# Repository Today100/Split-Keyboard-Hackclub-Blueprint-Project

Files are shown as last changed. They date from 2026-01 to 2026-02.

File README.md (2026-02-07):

# Split-Keyboard-Hackclub-Blueprint-Project
A split keyboard using the Seeed Studio XIAO nRF52840. Inspired by my dad, who likes looking at different kinds of keyboards. I'd like to make one to practice my skills in hardware design and give it to him as a gift. It has a Bluetooth feature and is rechargeable.

### Overview

|Part|Image|
|---|---|
|Full Product||
|Case||
|PCB||
|Schematics||

### BOM
BOM.csv is available for review

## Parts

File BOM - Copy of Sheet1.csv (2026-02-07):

Item | Amount | Amount | Store | Unit Price (USD) | Shipping (USD) | Tax (USD) | Total (USD) | Unit Price (CAD) | Shipping (CAD) | Tax (CAD) | Total (CAD) | Link
MBK Low Profile PBT Blank Keycaps Ocean | 6 (packs of 10) | 6 | Lowprokb | $4.38 | $7.30 | $4.36 | $37.94 | $6.00 | $10.00 | $5.98 | $51.98 | link
Kailh Choc V1 Low Profile Switches Red |  |  | Aliexpress | $21.01 | $5.32 | $0.00 | $62.45 | $28.79 | $7.29 | $0.00 | $85.60 | link
Kailh Choc Hot Swap Sockets CPG135001S30 |  |  |  | $14.52 |  |  |  | $19.89 |  |  |  | link
Microcontroller (Seeed XIAO nRF52840 BLE) |  |  |  | $21.59 |  |  |  | $29.58 |  |  |  | link
 |  |  |  |  |  |  | $100.39 |  |  |  | $137.58
 |  |  | Consider Possible Exchange Rate Difference, Produce Price Change, Request for: Extras will be returned to HackClub |  |  |  | $101.00 | USD

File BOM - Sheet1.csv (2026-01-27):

Item | Amount | Amount | Store | Unit Price (USD) | Shipping (USD) | Total (USD) | Unit Price (CAD) | Shipping (CAD) | Total (CAD) | Link
Microcontroller (Seeed XIAO nRF52840 BLE) | 2 | 2 | RobotShop | $10.37 | $5.76 | $34.33 | $14.21 | $7.89 | $47.03 | link
Female Pin Headers (1x7, 2.54mm pitch) | 2 | 2 | RobotShop | $2.04 |  |  | $2.79 |  |  | link
Male Pin Headers | 2 | 2 | RobotShop | $1.88 |  |  | $2.57 |  |  | link
Kailh Choc V1 Low Profile Switches Silver | 6 (packs of 10) | 6 | Lowprokb | $7.30 | $8.03 | $89.05 | $10.00 | $11.00 | $122.00 | link
Kailh Choc Hot Swap Sockets CPG135001S30 | 6 (packs of 10) | 6 | Lowprokb | $1.82 |  |  | $2.50 |  |  | link
MBK Low Profile PBT Blank Keycaps Ocean | 6 (packs of 10) | 6 | Lowprokb | $4.38 |  |  | $6.00 |  |  | link
10440 Battery 3.7V | 1 (pack of 2) | 1 | Amazon | $9.12 | $0.73 | $27.35 | $12.49 | $1.00 | $37.47 | link
Single AAA Battery Holder | 1 (pack of 12) | 1 | Amazon | $8.02 |  |  | $10.99 |  |  | link
Power Switch | 1 (packs of 150) | 1 | Amazon | $9.48 |  |  | $12.99 |  |  | link
2-in-1 MX & Choc Switch Opener | 1 | 1 | Print League | $0.00 | $7.30 | $7.30 | $0.00 | $10.00 | $10.00
Keyboard Case | 1 | 1 | Print League | $0.00 |  |  | $0.00
PCB Printing | 1 (set of 5) | 1 | JLCPCB | $18.09 | $28.99 | $57.02 | $24.78 | $39.71 | $78.12
Cost of Mounting |  |  | JLCPCB | $17.25 |  |  | $23.63
Discount | 1 | 1 | JLCPCB | -$7.30 |  |  | -$10.00
Diodes (1N4148, SOD-123 Surface Mount) | 52 | 52 | Solder on to the board directly (will reduce the cost of buying directly since the amount is little) | 0 | $0.00
Resistor R3 (806k Ω, SMD) | 2 | 2 | Solder on to the board directly (will reduce the cost of buying directly since the amount is little) | 0
Resistor R4 (2M Ω, SMD) | 2 | 2 | Solder on to the board directly (will reduce the cost of buying directly since the amount is little) | 0
 |  |  |  |  |  | $215.05 |  |  | $294.62
 |  |  | Consider Possible Exchange Rate Difference, Request for: Extras will be returned to HackClub |  |  | $220.00

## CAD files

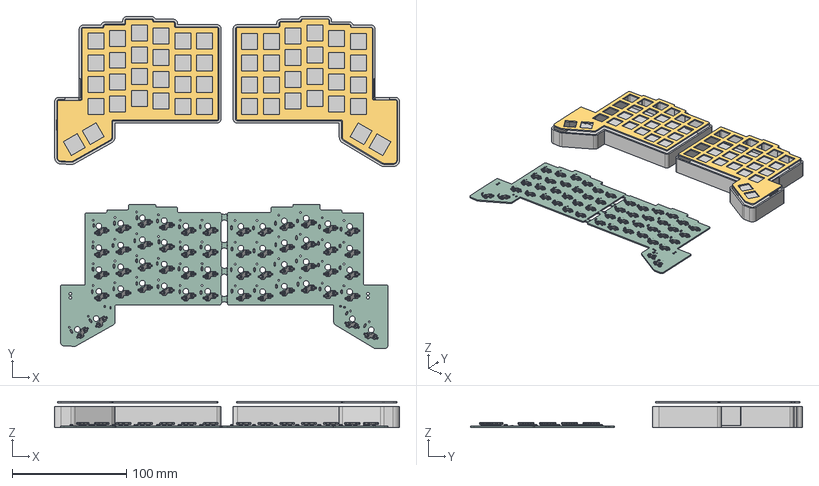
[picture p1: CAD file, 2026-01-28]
CAD/keyboard_case_and_pcb.step
302.2 x 290.6 x 22.9 mm

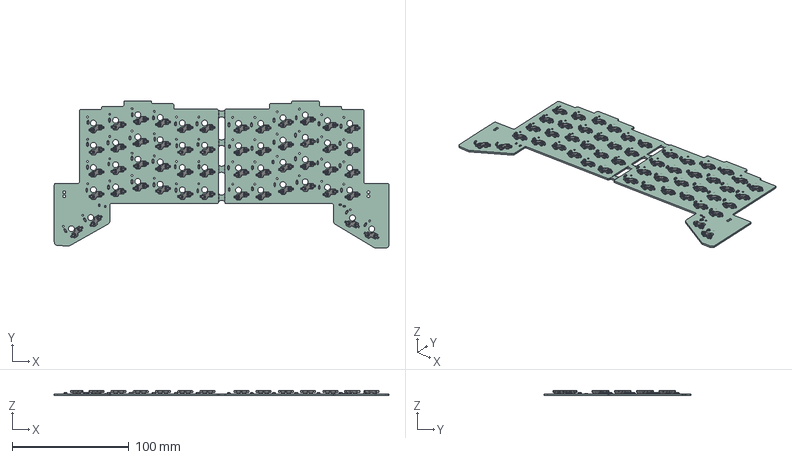
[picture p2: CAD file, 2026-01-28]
CAD/keyboard_pcb.step
287.0 x 126.2 x 4.63 mm

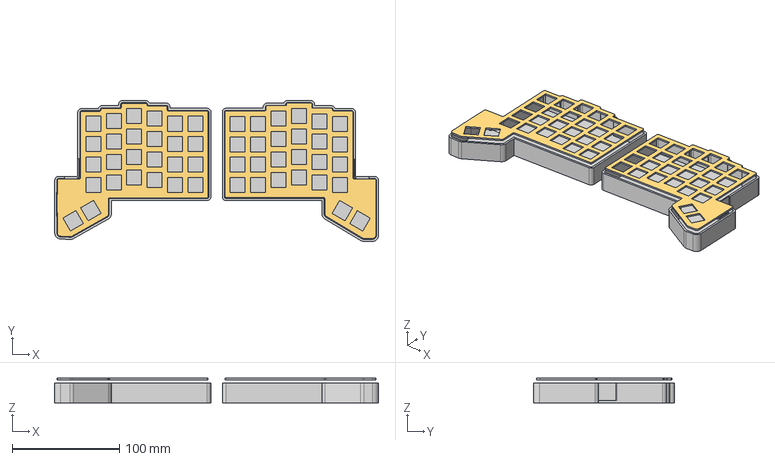
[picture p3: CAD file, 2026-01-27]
CAD/keyboard_case.step
302.2 x 131.4 x 22.9 mm

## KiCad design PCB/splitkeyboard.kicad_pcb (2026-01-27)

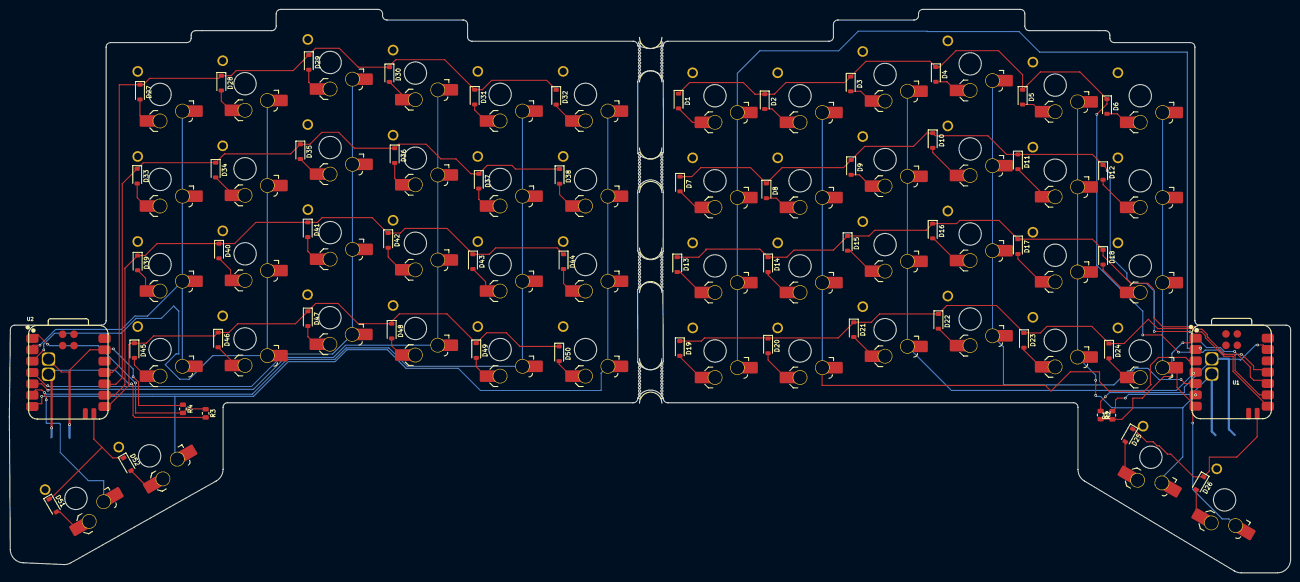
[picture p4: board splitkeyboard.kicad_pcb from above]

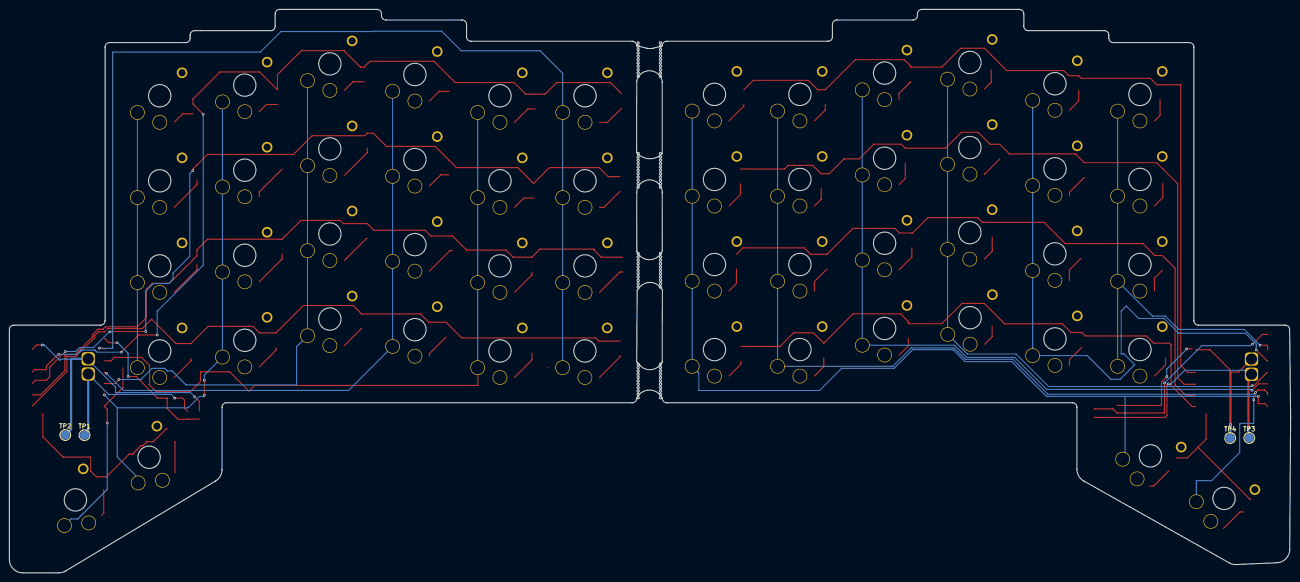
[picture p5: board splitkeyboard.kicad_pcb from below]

Board: 2 copper layers, 287.0 x 126.2 mm, 118 parts (4 on the bottom side), 79 nets.

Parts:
D1, D2, D3, D4, D5, D6, D7, D8, D9, D10, D11, D12, D13, D14, D15, D16, D17, D18, D19, D20, D21, D22, D23, D24, D25, D26, D27, D28, D29, D30, D31, D32, D33, D34, D35, D36, D37, D38, D39, D40, D41, D42, D43, D44, D45, D46, D47, D48, D49, D50, D51, D52: D; D_SOD-123
H1, H3, H4, H5: MountingHole; mouse-bite-5mm-slot
R1, R3: 806k; R_0805_2012Metric
R2, R4: 2M; R_0805_2012Metric
SW1, SW2, SW3, SW4, SW5, SW6, SW7, SW8, SW9, SW10, SW11, SW12, SW13, SW14, SW15, SW16, SW17, SW18, SW19, SW20, SW21, SW22, SW23, SW24, SW25, SW26, SW27, SW28, SW29, SW30, SW31, SW32, SW33, SW34, SW35, SW36, SW37, SW38, SW39, SW40, SW41, SW42, SW43, SW44, SW45, SW46, SW47, SW48, SW49, SW50, SW51, SW52: SW_Push; SW_choc_v2_HS_CPG135001S30_1u
TP1, TP3: BAT; TestPoint_Pad_D2.0mm
TP2, TP4: GND; TestPoint_Pad_D2.0mm
U1, U2: XIAO-nRF52840-SMD; modified-XIAO-nRF52840-SMD

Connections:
/left/BT_PIN: R1.1, R2.2, U1.1 (P0.02_A0_D0)
/left/COL0: SW1.1, SW7.1, SW13.1, SW19.1, U1.2 (P0.03_A1_D1)
/left/COL1: SW2.1, SW8.1, SW14.1, SW20.1, U1.3 (P0.28_A2_D2)
/left/COL2: SW3.1, SW9.1, SW15.1, SW21.1, U1.4 (P0.29_A3_D3)
/left/COL3: SW4.1, SW10.1, SW16.1, SW22.1, U1.5 (P0.04_A4_D4_SDA)
/left/COL4: SW5.1, SW11.1, SW17.1, SW23.1, SW25.1, U1.6 (P0.05_A5_D5_SCL)
/left/COL5: SW6.1, SW12.1, SW18.1, SW24.1, SW26.1, U1.7 (P1.11_D6_TX)
/left/ROW0: D1.1 (K), D2.1 (K), D3.1 (K), D4.1 (K), D5.1 (K), D6.1 (K), U1.11 (P1.15_D10_MOSI)
/left/ROW1: D7.1 (K), D8.1 (K), D9.1 (K), D10.1 (K), D11.1 (K), D12.1 (K), U1.10 (P1.14_D9_MISO)
/left/ROW2: D13.1 (K), D14.1 (K), D15.1 (K), D16.1 (K), D17.1 (K), D18.1 (K), U1.9 (P1.13_D8_SCK)
/left/ROW3: D19.1 (K), D20.1 (K), D21.1 (K), D22.1 (K), D23.1 (K), D24.1 (K), U1.8 (P1.12_D7_RX)
/left/ROW4: D25.1 (K), D26.1 (K), U1.18 (NFC2)
/left/VBAT: R1.2, TP1.1, U1.15 (BAT)
/right/BT_PIN: R3.1, R4.2, U2.1 (P0.02_A0_D0)
/right/COL0: SW27.1, SW33.1, SW39.1, SW45.1, U2.2 (P0.03_A1_D1)
/right/COL1: SW28.1, SW34.1, SW40.1, SW46.1, U2.3 (P0.28_A2_D2)
/right/COL2: SW29.1, SW35.1, SW41.1, SW47.1, U2.4 (P0.29_A3_D3)
/right/COL3: SW30.1, SW36.1, SW42.1, SW48.1, U2.5 (P0.04_A4_D4_SDA)
/right/COL4: SW31.1, SW37.1, SW43.1, SW49.1, SW51.1, U2.6 (P0.05_A5_D5_SCL)
/right/COL5: SW32.1, SW38.1, SW44.1, SW50.1, SW52.1, U2.7 (P1.11_D6_TX)
/right/ROW0: D27.1 (K), D28.1 (K), D29.1 (K), D30.1 (K), D31.1 (K), D32.1 (K), U2.11 (P1.15_D10_MOSI)
/right/ROW1: D33.1 (K), D34.1 (K), D35.1 (K), D36.1 (K), D37.1 (K), D38.1 (K), U2.10 (P1.14_D9_MISO)
/right/ROW2: D39.1 (K), D40.1 (K), D41.1 (K), D42.1 (K), D43.1 (K), D44.1 (K), U2.9 (P1.13_D8_SCK)
/right/ROW3: D45.1 (K), D46.1 (K), D47.1 (K), D48.1 (K), D49.1 (K), D50.1 (K), U2.8 (P1.12_D7_RX)
/right/ROW4: D51.1 (K), D52.1 (K), U2.18 (NFC2)
/right/VBAT: R3.2, TP3.1, U2.15 (BAT)
GND: R2.1, R4.1, TP2.1, TP4.1, U1.13 (GND), U1.16 (GND), U2.13 (GND), U2.16 (GND)
unnamed: D1.2 (A), SW1.2
unnamed: D2.2 (A), SW2.2
unnamed: D3.2 (A), SW3.2
unnamed: D4.2 (A), SW4.2
unnamed: D5.2 (A), SW5.2
unnamed: D6.2 (A), SW6.2
unnamed: D7.2 (A), SW7.2
unnamed: D8.2 (A), SW8.2
unnamed: D9.2 (A), SW9.2
unnamed: D10.2 (A), SW10.2
unnamed: D11.2 (A), SW11.2
unnamed: D12.2 (A), SW12.2
unnamed: D13.2 (A), SW13.2
unnamed: D14.2 (A), SW14.2
unnamed: D15.2 (A), SW15.2
unnamed: D16.2 (A), SW16.2
unnamed: D17.2 (A), SW17.2
unnamed: D18.2 (A), SW18.2
unnamed: D19.2 (A), SW19.2
unnamed: D20.2 (A), SW20.2
unnamed: D21.2 (A), SW21.2
unnamed: D22.2 (A), SW22.2
unnamed: D23.2 (A), SW23.2
unnamed: D24.2 (A), SW24.2
unnamed: D25.2 (A), SW25.2
unnamed: D26.2 (A), SW26.2
unnamed: D27.2 (A), SW27.2
unnamed: D28.2 (A), SW28.2
unnamed: D29.2 (A), SW29.2
unnamed: D30.2 (A), SW30.2
unnamed: D31.2 (A), SW31.2
unnamed: D32.2 (A), SW32.2
unnamed: D33.2 (A), SW33.2
unnamed: D34.2 (A), SW34.2
unnamed: D35.2 (A), SW35.2
unnamed: D36.2 (A), SW36.2
unnamed: D37.2 (A), SW37.2
unnamed: D38.2 (A), SW38.2
unnamed: D39.2 (A), SW39.2
unnamed: D40.2 (A), SW40.2
unnamed: D41.2 (A), SW41.2
unnamed: D42.2 (A), SW42.2
unnamed: D43.2 (A), SW43.2
unnamed: D44.2 (A), SW44.2
unnamed: D45.2 (A), SW45.2
unnamed: D46.2 (A), SW46.2
unnamed: D47.2 (A), SW47.2
unnamed: D48.2 (A), SW48.2
unnamed: D49.2 (A), SW49.2
unnamed: D50.2 (A), SW50.2
unnamed: D51.2 (A), SW51.2
unnamed: D52.2 (A), SW52.2

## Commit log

2026-01-20 Remove placeholder file CAD/placeholder
2026-01-20 Add BOM section to README
    Added a Bill of Materials (BOM) section with item details.
2026-01-20 Revise README with new components and pricing
    Updated component list with additional items and links, including diodes, resistors, and power switch.
2026-01-27 Update and rename BOM - Sheet1.csv to BOM.csv
    [BOM.csv]
2026-01-28 Revise BOM with updated pricing and sources
    Updated BOM section with detailed cost breakdown and links.
2026-01-28 Add product links and fix BOM formatting
    Updated BOM.csv to include product links and corrected formatting.
    [BOM.csv]
2026-01-28 Restore BOM.csv with updated item details
    Restored BOM.csv with updated item entries and prices.
    [BOM.csv]
2026-02-07 Update BOM - Copy of Sheet1.csv with new entries
    Removed old data and added new BOM entries.
    [BOM - Copy of Sheet1.csv]
2026-02-07 Update and rename BOM - Copy of Sheet1.csv to BOM.csv
    [BOM.csv]
2026-02-07 Remove detailed BOM table from README
